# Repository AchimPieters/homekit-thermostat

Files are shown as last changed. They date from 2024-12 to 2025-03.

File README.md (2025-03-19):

# Homekit Thermostat

> *If you want a smart thermostat that supports Homekit, they are usually quite expensive (\$150+), that's why I decided to build one myself and it cost me less than $40*

https://github.com/user-attachments/assets/f03cbc0a-a529-49a5-ae72-671e549893d3

## How it works

This thermostat is built on **ESP32** and features an **LCD display** with a **touch screen**. The graphic interface is created using the **LVGL** library, allowing you to adjust the required temperature. It connects to a Wi-Fi network that is first configured using a **network provisioning** process and keeps its time accurate thanks to the **NTP** protocol. It uses Achim Pieters' [HomeKit library](https://github.com/AchimPieters/esp32-homekit) to communicate with the **Apple Home app**. The **SHT-40 sensor** measures the temperature, and the **relay** switches a boiler on or off based on the set temperature conditions.

### WiFi provisioning
The ESP32 uses Bluetooth Low Energy (BLE) to make the Wi-Fi provisioning process simple. When the device starts up, it creates a BLE service that can be detected by the BLE Provisioning app. Using the app, you can scan for available Wi-Fi networks, select one, and send the credentials to the ESP32. The device then connects to the provided network and saves the credentials for future use. This process ensures the device can be set up without hardcoding any Wi-Fi details.

This process is only necessary after the first start where the setup screen with a QR code will be displayed.<br/>
Install the [ESP Provisioning](https://apps.apple.com/us/app/esp-ble-provisioning/id1473590141) app and scan the QR code to configure your WiFi network credentials first. <br/>
After that, the Wi-Fi credentials will be stored on the device and the thermostat can connect to the configured Wi-Fi network automatically.

<p align="center">
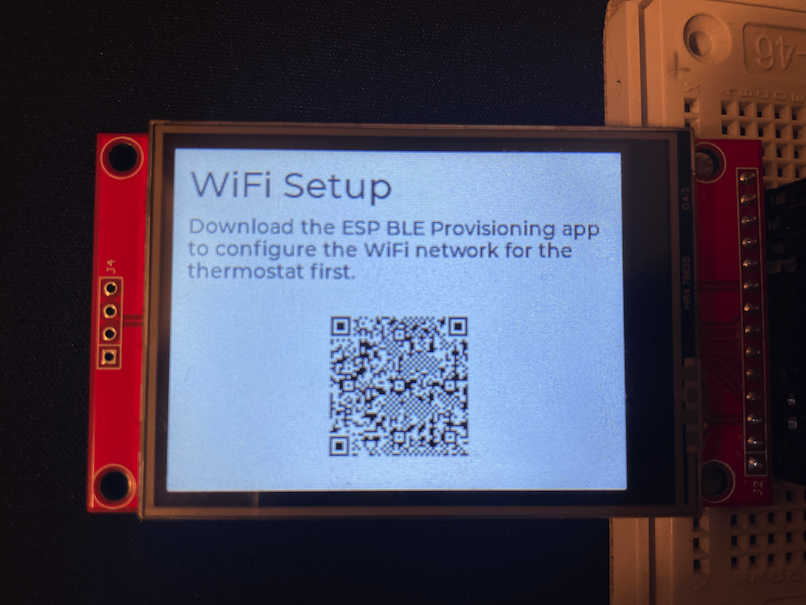
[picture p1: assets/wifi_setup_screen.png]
  
</p>

### Homekit Setup
Once you have the Wi-Fi network configured, you can add the thermostat to your Apple Home app. To do that, scan the following QR code.<br/>
Unfortunately, these two actions cannot be done in a single step (using one QR code), as Apple doesn't support WiFi provisioning for [MFi](https://mfi.apple.com/) uncertified (custom) Homekit devices. 

<p align="center">
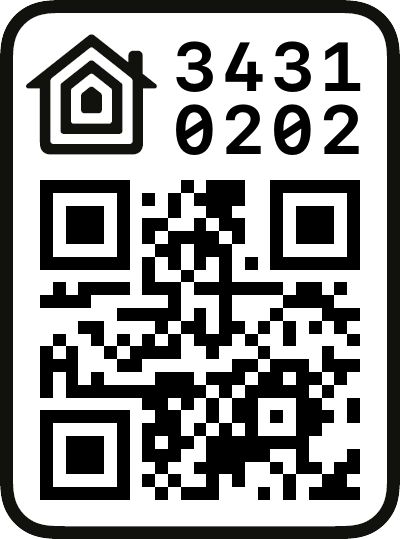
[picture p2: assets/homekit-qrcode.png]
  
</p>

### Time sync
The thermostat uses NTP protocol to sync the current time with the internet servers after it starts up. This ensures that the device always has accurate time.

### GUI

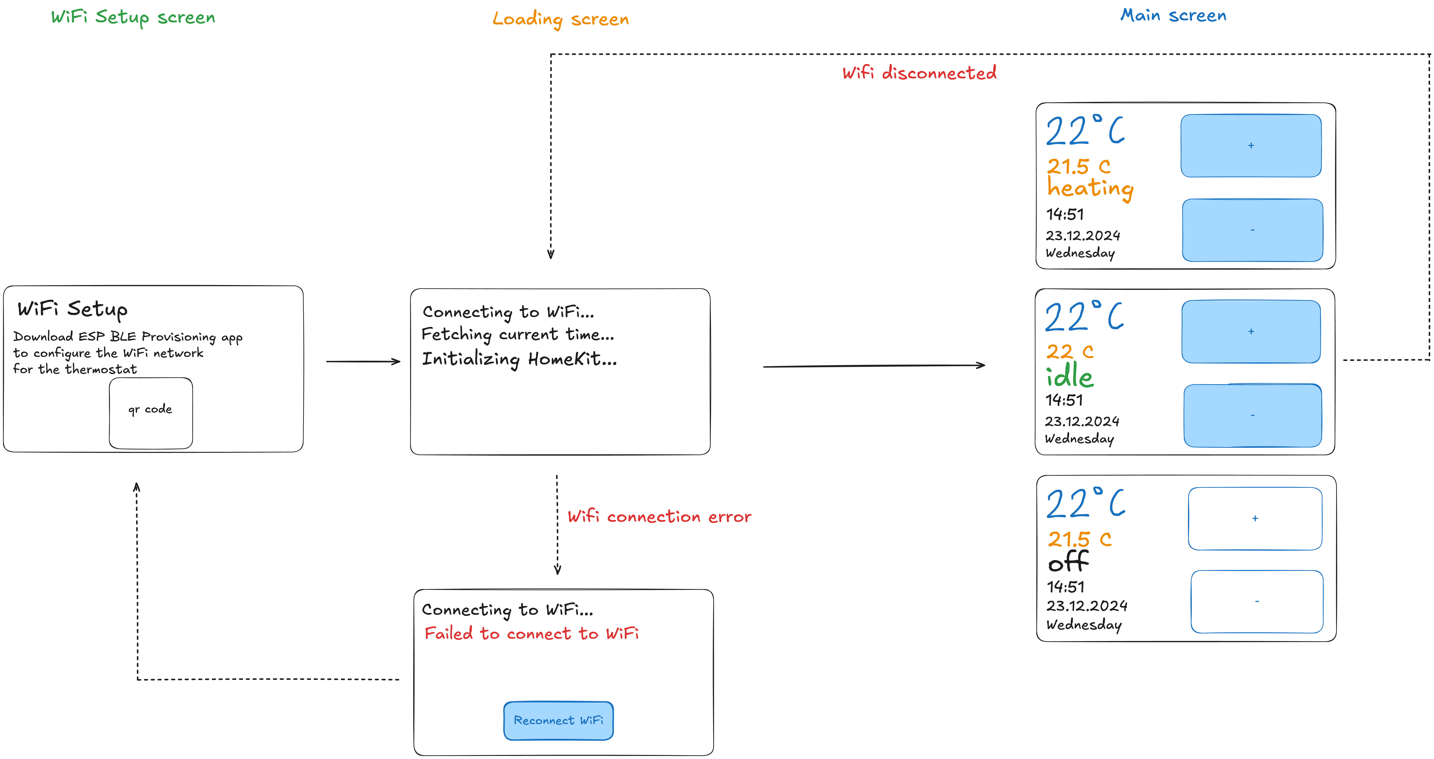
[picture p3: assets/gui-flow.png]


This thermostat consists of 3 different GUI screens that can be shown on the LCD display.<br/>The UI is built using [LVGL 8.3](https://lvgl.io/).

#### WiFi setup screen
This is the first screen the user sees when the thermostat is turned on for the first time.
On this screen, you can set up a Wi-fi network.

#### Loading screen
Once the Wi-fi network is selected, this screen is automatically displayed, showing initialization logs. <br/> If the Wi-fi connection fails after 5 attempts, it will display the "Reconnect Wi-fi" button which will restart the provisioning flow. <br/>
This screen is also displayed when the thermostat has been running and the Wi-fi connection is suddenly lost.

#### Main screen
This screen is displayed after everything has been initialized (WiFi, Homekit server, time, etc.). You can view the current room temperature, date & time and control the desired temperature.<br/>
This is a two-way sync, so whenever the temperature update happens, either in a Homekit app or here on the screen, via the manual touch interaction, it will be propagated to the other side too.

### Electrical circuit
This circuit uses an [ESP32-C6](https://www.laskakit.cz/en/espressif-esp32-c6-devkitm-1-wifi-6--bluetooth-5--zigbee/) microcontroller board with the following peripherals:

<p align="center">
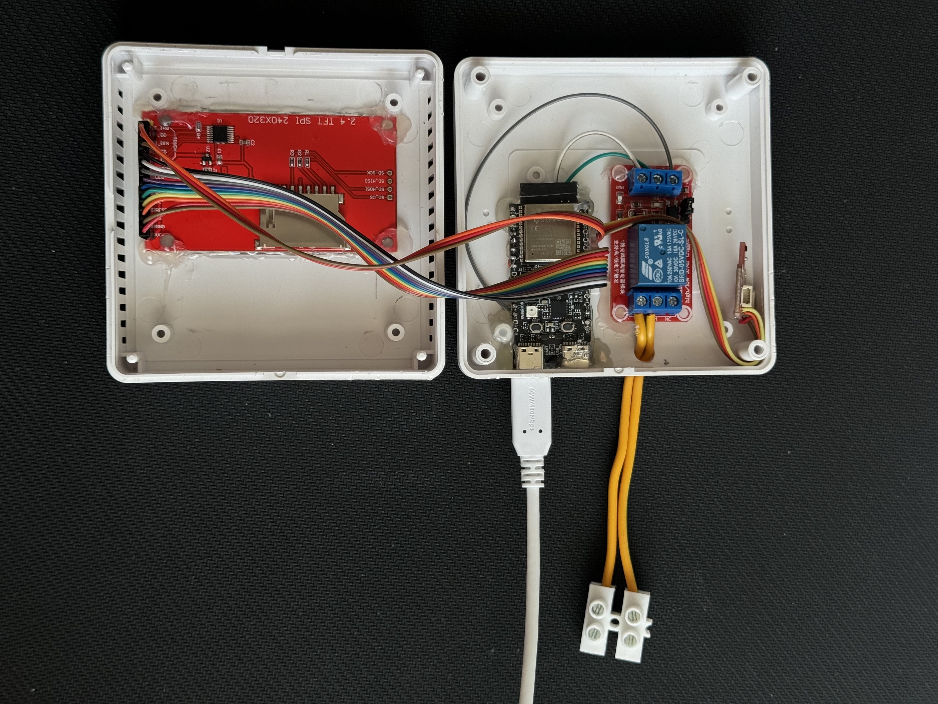
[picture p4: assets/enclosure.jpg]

</p>

<p align="center">
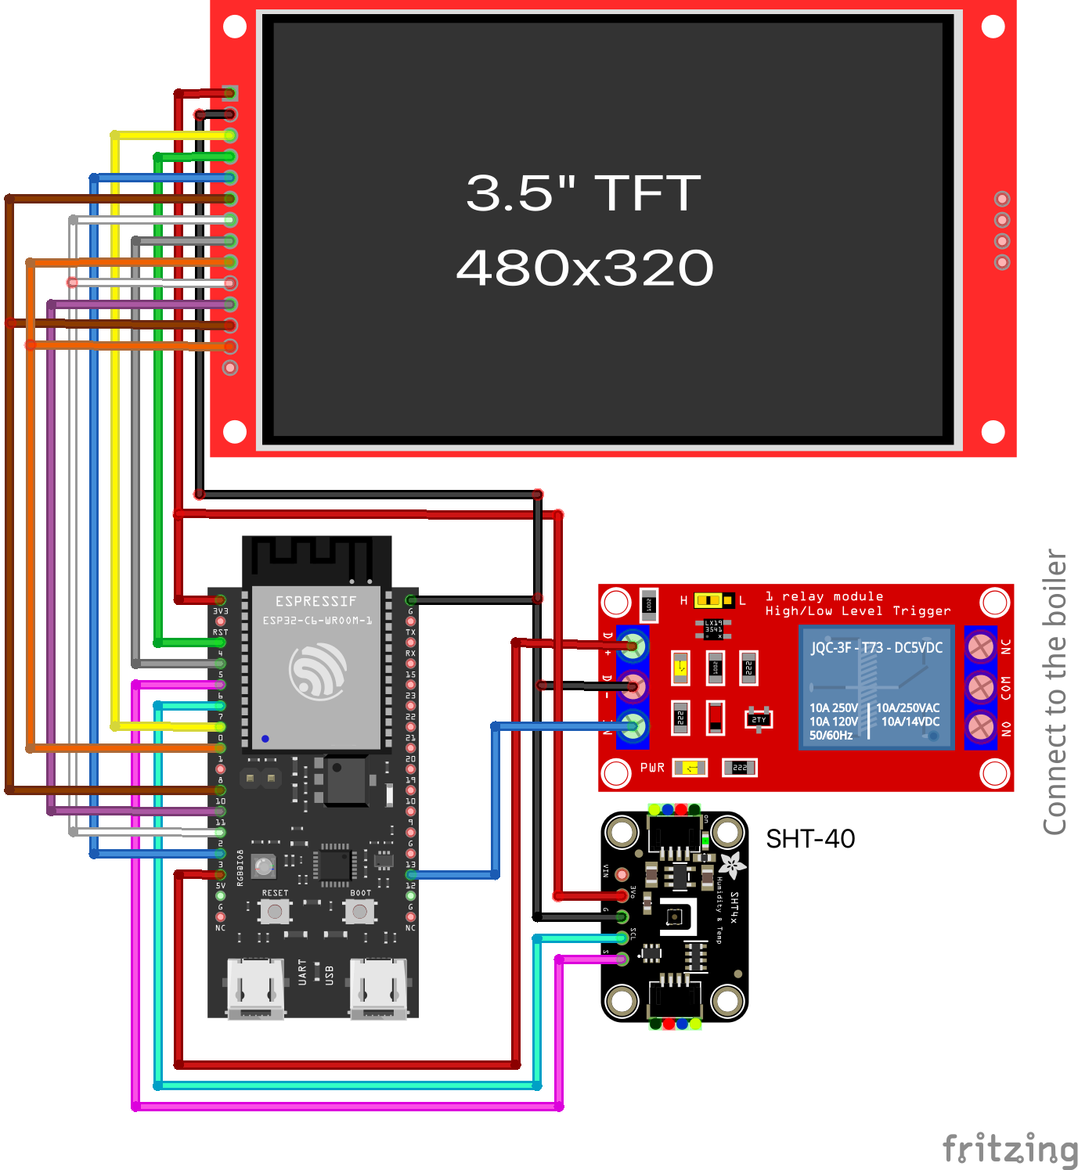
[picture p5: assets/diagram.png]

</p>

#### Thermometer
For the temperature measuring, this project uses a [SHT-40](https://www.laskakit.cz/en/laskakit-sht40-senzor-teploty-a-vlhkosti-vzduchu/) sensor. It communicates with the ESP32 via I2C and measures the current temperature and humidity every minute.

| SHT-40 | ESP32 |
| --- | ---- |
| VCC | 3.3V |
| GND | GND  |
| SDA | 6 |
| SCL | 7 |

#### Relay
Once the temperature drops below the target threshold, ESP32 sends a signal to the [5V relay](https://www.laskakit.cz/en/1-kanal-5v-rele-modul-s-optickym-oddelenim--high-low-level--250vac-10a/) to turn on the boiler. Once the room reaches the required temperature, the relay will be switched off.

| Relay | ESP32 |
| --- | ---- |
| VCC | 5V |
| GND | GND  |
| IN | 12 |

#### LCD screen
This termostat is equiped with a [2.4" LCD display](https://www.laskakit.cz/en/2-4--palcovy-barevny-dotykovy-tft-lcd-displej-240x320-ili9341-spi/) with a touch screen that is connected via SPI. Both the LCD and the touchscreen share the same SPI connection.

| LCD | ESP32 |
| --- | ---- |
| VCC | 3.3V |
| GND | GND  |
| SCLK | 2  |
| MISO | 1  |
| MOSI | 10  |
| DC | 3 |
| Reset | 4 |
| CS | 0 |
| Backlight | 5 |
| T_CS | 11 |
| T_CLK | 2  |
| T_MISO | 1 |
| T_MOSI | 10 |

## 3rd party libraries
This project wouldn't be possible without these awesome libraries.

- [esp32-homekit](https://github.com/AchimPieters/esp32-homekit) by [@AchimPieters](https://github.com/AchimPieters)
- [i2cdev](https://github.com/UncleRus/esp-idf-lib/tree/master/components/i2cdev), [sht4x](https://github.com/UncleRus/esp-idf-lib/tree/master/components/sht4x) by [@UncleRus](https://github.com/UncleRus)
- [lv_qrcode](https://github.com/lvgl/lv_lib_qrcode) by [@lvgl](https://github.com/lvgl)

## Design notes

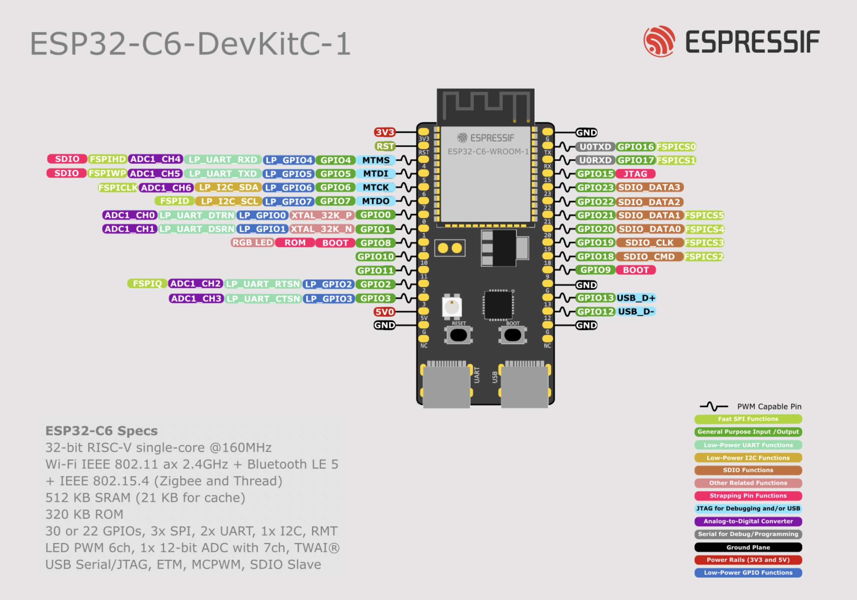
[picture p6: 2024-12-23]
assets/esp32c6.jpg

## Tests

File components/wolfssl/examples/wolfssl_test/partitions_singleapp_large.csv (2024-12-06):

# This tag is used to include this file in the ESP Component Registry:
# __ESP_COMPONENT_SOURCE__
# to view: idf.py partition-table
#
# ESP-IDF Partition Table
# Name | Type | SubType | Offset | Size | Flags
nvs | data | nvs | 0x9000 | 24K
phy_init | data | phy | 0xf000 | 4K
factory | app | factory | 0x10000 | 1500K
# For other settings | see:
# https://docs.espressif.com/projects/esp-idf/en/latest/esp32/api-guides/partition-tables.html
#
# Here is the summary printed for the “Single factory app | no OTA” configuration:
#
# # ESP-IDF Partition Table
# # Name | Type | SubType | Offset | Size | Flags
# nvs | data | nvs | 0x9000 | 0x6000
# phy_init | data | phy | 0xf000 | 0x1000
# factory | app | factory | 0x10000 | 1M
#
#
# Here is the summary printed for the “Factory app | two OTA definitions” configuration:
#
# # ESP-IDF Partition Table
# # Name | Type | SubType | Offset | Size | Flags
# nvs | data | nvs | 0x9000 | 0x4000
# otadata | data | ota | 0xd000 | 0x2000
# phy_init | data | phy | 0xf000 | 0x1000
# factory | app | factory | 0x10000 | 1M
# ota_0 | app | ota_0 | 0x110000 | 1M
# ota_1 | app | ota_1 | 0x210000 | 1M

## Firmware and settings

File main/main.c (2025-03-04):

#include <esp_err.h>
#include <esp_event.h>
#include <esp_log.h>
#include <freertos/FreeRTOS.h>
#include <freertos/task.h>
#include <nvs_flash.h>
#include <stdio.h>

#include "datetime.h"
#include "events.h"
#include "gui/gui.h"
#include "gui/scr_loading.h"
#include "gui/scr_main.h"
#include "gui/scr_wifi_setup.h"
#include "homekit.h"
#include "hw/lcd.h"
#include "hw/led.h"
#include "hw/relay.h"
#include "hw/sht40.h"
#include "wifi.h"
#include "tasks/tasks.h"

static bool thermostat_initialized = false;
static int failed_wifi_attempts = 0;
static bool should_wifi_retry = true;

void on_homekit_update(HomekitState state) {
  // If the target state is set to either OFF or to one of unsupported states,
  // turn the thermostat off
  if (state.target_state == THERMOSTAT_OFF || state.target_state == _THERMOSTAT_AUTO || state.target_state == _THERMOSTAT_COOL) {
    homekit_set_thermostat_status(THERMOSTAT_OFF);
    relay_off();
    gui_set_thermostat_status(THERMOSTAT_OFF);

    return;
  }

  // Otherwise, make sure the current state is set to HEAT
  homekit_set_thermostat_status(THERMOSTAT_HEAT);

  if (state.current_temp < state.target_temp) {
    if (!relay_turned_on) {
      ESP_LOGI("HOMEKIT_UPDATE", "Current temperature (%.1f) is lower than the target (%.1f). Switching relay ON", state.current_temp, state.target_temp);
      relay_on();
    }
    gui_set_thermostat_status(THERMOSTAT_HEAT);
  } else if (state.current_temp >= state.target_temp) {
    if (relay_turned_on) {
      ESP_LOGI("HOMEKIT_UPDATE", "Current temperature (%.1f) is higher or equal than the target (%.1f). Switching relay OFF", state.current_temp, state.target_temp);
      relay_off();
    }
    gui_set_thermostat_status(_THERMOSTAT_IDLE);
  }

  // Update target temperature in GUI
  gui_set_target_temp(state.target_temp);
}

void restart_wifi_prov() {
  // Ideally we would show the QR code screen again and restart the provisioning flow
  // But this motherfucker keeps crashing and I already spent too much time trying to make it work
  // while it might never be actually used at all. So fuck this shit.
  // I'll just restart the whole ESP32 board and start over.
  wifi_reset();
  esp_restart();
}

void on_temp_btn(ButtonType type) {
  float target_value = homekit_get_state().target_temp;

  // Update target temperature
  float new_temp = 0;
  if (type == BUTTON_INCREASE) {
    new_temp = target_value + 0.5;
    if (new_temp > CONFIG_THERMOSTAT_MAX_TEMP) {
      new_temp = CONFIG_THERMOSTAT_MAX_TEMP;
    }
  } else if (type == BUTTON_DECREASE) {
    new_temp = target_value - 0.5;

    if (new_temp < CONFIG_THERMOSTAT_MIN_TEMP) {
      new_temp = CONFIG_THERMOSTAT_MIN_TEMP;
    }
  }

  // Update homekit
  homekit_set_target_temp(new_temp);

  // Update GUI
  gui_set_target_temp(new_temp);
}

void on_eventloop_evt(void *arg, esp_event_base_t event_base, int32_t event_id, void *event_data) {
  const char *tag = "EVENT";
  switch (event_id) {
    case HOMEKIT_THERMOSTAT_WIFI_REQUEST_PROVISIONING:
      // Init the provisioning and display the QR code
      ESP_LOGI(tag, "Received WiFi provisioning request.");
      char qr_data[150] = {0};
      if (wifi_init_provisioning(qr_data, sizeof(qr_data)) == -1) {
        restart_wifi_prov();
      } else {
        gui_wifi_scr(qr_data, sizeof(qr_data));
      }
      failed_wifi_attempts = 0;
      break;
    case HOMEKIT_THERMOSTAT_WIFI_CONNECTED:
      ESP_LOGI(tag, "WiFi connected.");
      // Fetch the current time from the internet
      datetime_init();

      // Start the Homekit server
      homekit_init(on_homekit_update);

      eventloop_dispatch(HOMEKIT_THERMOSTAT_INIT_DONE, NULL, 0);
      break;
    case HOMEKIT_THERMOSTAT_WIFI_DISCONNECTED:
      ESP_LOGI(tag, "WiFi disconnected.");

      if (!should_wifi_retry) {
        break;
      }

      // If WiFi goes down, first show the loading screen so we can communicate with the user 
      gui_loading_scr();

      // If thermostat hasn't been initialized yet, it means it wasn't able to connect to the WiFi after starting
      // In that case, show the Reconnect WiFi button after 5 failed attempts
      if (!thermostat_initialized) {
        if (++failed_wifi_attempts >= 5) {
          gui_loading_show_reconnect_btn(restart_wifi_prov);
          should_wifi_retry = false;
        } {
          // Try to reconnect
          printf("reconnecting because not initialized and attempts >= 5 (%d)\n", failed_wifi_attempts);
          wifi_reconnect();
        }
      } else {
        // Otherwise if the thermostat has been already initialized,
        // keep reconnecting forever (until the connection comes back up)
        printf("reconnecting forever because initialized \n");
        wifi_reconnect();
      }
      break;
    case HOMEKIT_THERMOSTAT_INIT_STARTED:
      ESP_LOGI(tag, "Initialization started.");
      gui_loading_scr();
      break;
    case HOMEKIT_THERMOSTAT_LOG:
      if (event_data != NULL) {
        gui_loading_add_log((char *)event_data);
      }
      break;
    case HOMEKIT_THERMOSTAT_INIT_DONE:
      ESP_LOGI(tag, "Homekit thermostat is ready.");
      gui_main_scr();

      // Start the temperature check task
      xTaskCreate(task_temperature, "TempTask", configMINIMAL_STACK_SIZE * 3, NULL, 5, NULL);

      // Start the time update task
      xTaskCreate(task_time, "TimeTask", configMINIMAL_STACK_SIZE * 3, NULL, 5, NULL);

      // Set initial data in Homekit
      TempHumidity temp_humid = sht40_measure_temp();
      homekit_set_curr_temp(temp_humid);
      homekit_set_thermostat_status(THERMOSTAT_HEAT);

      // Show initial data in GUI
      HomekitState state = homekit_get_state();
      gui_set_curr_temp(temp_humid.temperature);
      gui_set_target_temp(state.target_temp);
      gui_set_thermostat_status(state.current_temp >= state.target_temp ? _THERMOSTAT_IDLE : THERMOSTAT_HEAT);

      // Register temperature buttons handler
      gui_on_btn_pressed_cb(on_temp_btn);

      thermostat_initialized = true;
      break;
  }
}

void app_main() {
  // Init storage
  esp_err_t ret = nvs_flash_init();
  if (ret == ESP_ERR_NVS_NO_FREE_PAGES || ret == ESP_ERR_NVS_NEW_VERSION_FOUND) {
    ESP_LOGW("WARNING", "NVS flash initialization failed, erasing...");
    ESP_ERROR_CHECK(nvs_flash_erase());
    ret = nvs_flash_init();
  }
  ESP_ERROR_CHECK(ret);

  // Init peripherals
  led_disable();
  sht40_init();
  relay_init();

  // Init display
  lcd_init();
  gui_init();

  // Init default event loop
  ESP_ERROR_CHECK(esp_event_loop_create_default());

  // Init Homekit Thermostat event loop
  eventloop_init(on_eventloop_evt);

  // Init WiFi
  wifi_init();

  if (!wifi_is_provisioned()) {
    eventloop_dispatch(HOMEKIT_THERMOSTAT_WIFI_REQUEST_PROVISIONING, NULL, 0);
  } else {
    eventloop_dispatch(HOMEKIT_THERMOSTAT_INIT_STARTED, NULL, 0);
    wifi_connect();
  }
}

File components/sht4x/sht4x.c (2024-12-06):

/*
 * Copyright (c) 2021 Ruslan V. Uss <unclerus@gmail.com>
 *
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
 * THIS SOFTWARE IS PROVIDED BY THE COPYRIGHT HOLDERS AND CONTRIBUTORS "AS IS"
 * AND ANY EXPRESS OR IMPLIED WARRANTIES, INCLUDING, BUT NOT LIMITED TO, THE
 * IMPLIED WARRANTIES OF MERCHANTABILITY AND FITNESS FOR A PARTICULAR PURPOSE ARE
 * DISCLAIMED. IN NO EVENT SHALL THE COPYRIGHT HOLDER OR CONTRIBUTORS BE LIABLE
 * FOR ANY DIRECT, INDIRECT, INCIDENTAL, SPECIAL, EXEMPLARY, OR CONSEQUENTIAL
 * DAMAGES (INCLUDING, BUT NOT LIMITED TO, PROCUREMENT OF SUBSTITUTE GOODS OR
 * SERVICES; LOSS OF USE, DATA, OR PROFITS; OR BUSINESS INTERRUPTION) HOWEVER
 * CAUSED AND ON ANY THEORY OF LIABILITY, WHETHER IN CONTRACT, STRICT LIABILITY,
 * OR TORT (INCLUDING NEGLIGENCE OR OTHERWISE) ARISING IN ANY WAY OUT OF THE USE
 * OF THIS SOFTWARE, EVEN IF ADVISED OF THE POSSIBILITY OF SUCH DAMAGE.
 */

/**
 * @file sht4x.c
 *
 * ESP-IDF driver for Sensirion SHT40/SHT41 digital temperature and humidity sensor
 *
 * Copyright (c) 2021 Ruslan V. Uss <unclerus@gmail.com>
 *
 * BSD Licensed as described in the file LICENSE
 */

#include <esp_log.h>
#include <freertos/FreeRTOS.h>
#include <freertos/task.h>
#include <esp_idf_lib_helpers.h>
#include <esp_timer.h>
#include "sht4x.h"

#define I2C_FREQ_HZ 1000000 // 1MHz

// due to the fact that ticks can be smaller than portTICK_PERIOD_MS, one and
// a half tick period added to the duration to be sure that waiting time for
// the results is long enough
#define TIME_TO_TICKS(ms) (1 + ((ms) + (portTICK_PERIOD_MS-1) + portTICK_PERIOD_MS/2 ) / portTICK_PERIOD_MS)

static const char *TAG = "sht4x";

#define CMD_RESET             0x94
#define CMD_SERIAL            0x89
#define CMD_MEAS_HIGH         0xfd
#define CMD_MEAS_MED          0xf6
#define CMD_MEAS_LOW          0xe0
#define CMD_MEAS_H_HIGH_LONG  0x39
#define CMD_MEAS_H_HIGH_SHORT 0x32
#define CMD_MEAS_H_MED_LONG   0x2f
#define CMD_MEAS_H_MED_SHORT  0x24
#define CMD_MEAS_H_LOW_LONG   0x1e
#define CMD_MEAS_H_LOW_SHORT  0x15

#define CHECK(x) do { esp_err_t __; if ((__ = x) != ESP_OK) return __; } while (0)
#define CHECK_ARG(VAL) do { if (!(VAL)) return ESP_ERR_INVALID_ARG; } while (0)

#define G_POLYNOM 0x31

static uint8_t crc8(uint8_t data[], size_t len)
{
    uint8_t crc = 0xff;

    for (size_t i = 0; i < len; i++)
    {
        crc ^= data[i];
        for (size_t i = 0; i < 8; i++)
            crc = crc & 0x80 ? (crc << 1) ^ G_POLYNOM : crc << 1;
    }
    return crc;
}

static inline size_t get_duration_ms(sht4x_t *dev)
{
    switch (dev->heater)
    {
        case SHT4X_HEATER_HIGH_LONG:
        case SHT4X_HEATER_MEDIUM_LONG:
        case SHT4X_HEATER_LOW_LONG:
            return 1100;
        case SHT4X_HEATER_HIGH_SHORT:
        case SHT4X_HEATER_MEDIUM_SHORT:
        case SHT4X_HEATER_LOW_SHORT:
            return 110;
        default:
            switch (dev->repeatability)
            {
                case SHT4X_HIGH:
                    return 10;
                case SHT4X_MEDIUM:
                    return 5;
                default:
                    return 2;
            }
    }
}

static inline uint8_t get_meas_cmd(sht4x_t *dev)
{
    switch (dev->heater)
    {
        case SHT4X_HEATER_HIGH_LONG:
            return CMD_MEAS_H_HIGH_LONG;
        case SHT4X_HEATER_HIGH_SHORT:
            return CMD_MEAS_H_HIGH_SHORT;
        case SHT4X_HEATER_MEDIUM_LONG:
            return CMD_MEAS_H_MED_LONG;
        case SHT4X_HEATER_MEDIUM_SHORT:
            return CMD_MEAS_H_MED_SHORT;
        case SHT4X_HEATER_LOW_LONG:
            return CMD_MEAS_H_LOW_LONG;
        case SHT4X_HEATER_LOW_SHORT:
            return CMD_MEAS_H_LOW_SHORT;
        default:
            switch (dev->repeatability)
            {
                case SHT4X_HIGH:
                    return CMD_MEAS_HIGH;
                case SHT4X_MEDIUM:
                    return CMD_MEAS_MED;
                default:
                    return CMD_MEAS_LOW;
            }
    }
}

static inline esp_err_t send_cmd_nolock(sht4x_t *dev, uint8_t cmd)
{
    ESP_LOGD(TAG, "Sending cmd %02x...", cmd);
    return i2c_dev_write(&dev->i2c_dev, NULL, 0, &cmd, 1);
}

static inline esp_err_t read_res_nolock(sht4x_t *dev, sht4x_raw_data_t res)
{
    CHECK(i2c_dev_read(&dev->i2c_dev, NULL, 0, res, SHT4X_RAW_DATA_SIZE));

    ESP_LOGD(TAG, "Got response %02x %02x %02x %02x %02x %02x",
            res[0], res[1], res[2], res[3], res[4], res[5]);

    if (res[2] != crc8(res, 2) || res[5] != crc8(res + 3, 2))
    {
        ESP_LOGE(TAG, "Invalid CRC");
        return ESP_ERR_INVALID_CRC;
    }

    return ESP_OK;
}

static esp_err_t send_cmd(sht4x_t *dev, uint8_t cmd)
{
    I2C_DEV_TAKE_MUTEX(&dev->i2c_dev);
    I2C_DEV_CHECK(&dev->i2c_dev, send_cmd_nolock(dev, cmd));
    I2C_DEV_GIVE_MUTEX(&dev->i2c_dev);

    return ESP_OK;
}

static esp_err_t read_res(sht4x_t *dev, sht4x_raw_data_t res)
{
    I2C_DEV_TAKE_MUTEX(&dev->i2c_dev);
    I2C_DEV_CHECK(&dev->i2c_dev, read_res_nolock(dev, res));
    I2C_DEV_GIVE_MUTEX(&dev->i2c_dev);

    return ESP_OK;
}

static esp_err_t exec_cmd(sht4x_t *dev, uint8_t cmd, size_t delay_ticks, sht4x_raw_data_t res)
{
    I2C_DEV_TAKE_MUTEX(&dev->i2c_dev);
    I2C_DEV_CHECK(&dev->i2c_dev, send_cmd_nolock(dev, cmd));
    vTaskDelay(delay_ticks + 1);
    I2C_DEV_CHECK(&dev->i2c_dev, read_res_nolock(dev, res));
    I2C_DEV_GIVE_MUTEX(&dev->i2c_dev);

    return ESP_OK;
}

static inline bool is_measuring(sht4x_t *dev)
{
    // not running if measurement is not started
    if (!dev->meas_started)
      return false;

    // not running if time elapsed is greater than duration
    uint64_t elapsed = esp_timer_get_time() - dev->meas_start_time;
    return elapsed < get_duration_ms(dev) * 1000;
}

///////////////////////////////////////////////////////////////////////////////

esp_err_t sht4x_init_desc(sht4x_t *dev, i2c_port_t port, gpio_num_t sda_gpio, gpio_num_t scl_gpio)
{
    CHECK_ARG(dev);

    dev->i2c_dev.port = port;
    dev->i2c_dev.addr = SHT4X_I2C_ADDRESS;
    dev->i2c_dev.cfg.sda_io_num = sda_gpio;
    dev->i2c_dev.cfg.scl_io_num = scl_gpio;
#if HELPER_TARGET_IS_ESP32
    dev->i2c_dev.cfg.master.clk_speed = I2C_FREQ_HZ;
#endif

    return i2c_dev_create_mutex(&dev->i2c_dev);
}

esp_err_t sht4x_free_desc(sht4x_t *dev)
{
    CHECK_ARG(dev);

    return i2c_dev_delete_mutex(&dev->i2c_dev);
}

esp_err_t sht4x_init(sht4x_t *dev)
{
    CHECK_ARG(dev);

    dev->repeatability = SHT4X_HIGH;
    dev->heater = SHT4X_HEATER_OFF;

    sht4x_raw_data_t s;
    CHECK(exec_cmd(dev, CMD_SERIAL, TIME_TO_TICKS(10), s));
    dev->serial = ((uint32_t)s[0] << 24) | ((uint32_t)s[1] << 16) | ((uint32_t)s[3] << 8) | s[4];

    return sht4x_reset(dev);
}

esp_err_t sht4x_reset(sht4x_t *dev)
{
    dev->meas_start_time = 0;
    dev->meas_started = false;

    CHECK(send_cmd(dev, CMD_RESET));
    vTaskDelay(1);

    return ESP_OK;
}
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

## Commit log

2024-12-06 feat(deps): wolfssl
    [partitions_singleapp_large.csv]
2024-12-06 feat(deps): i2cdev
2024-12-10 feat: connect temperature sensor
    [partitions_esp32c6.csv]
2024-12-10 feat: connect relay
2024-12-13 fix(homekit): move pointer outside of function
    [partitions.csv, partitions_esp32c6.csv]
2025-01-13 feat: get/set homekit target temperature
2025-02-09 feat: homekit temperature logic
2025-02-11 feat: refactor LCD wiring
    [thermostat.fzz]
2025-02-12 fix: restart wifi provisioning
    [main.c]
2025-02-20 feat: change temperature by 0.5 degree
2025-03-01 fix: relay gpio config
    [relay.c]
2025-03-03 fix: temperature condition & color
    [main.c]
2025-03-04 fix: explicitly disable builtin LED
    [main.c]
2025-03-06 fix: add temperature offset
